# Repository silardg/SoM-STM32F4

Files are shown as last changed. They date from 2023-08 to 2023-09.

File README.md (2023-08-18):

# SoM STM32F4

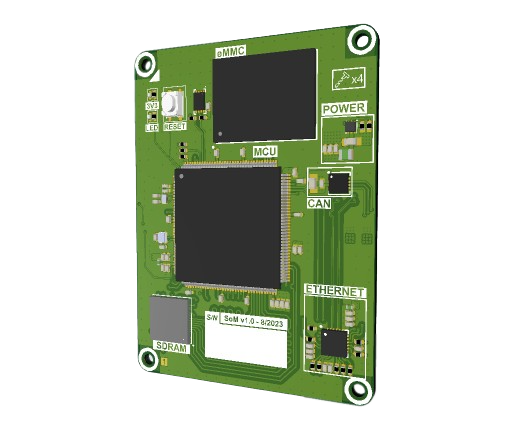
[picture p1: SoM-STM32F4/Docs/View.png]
BoardView


This System-on-Module provides a powerful platform with an STM32F429 extended by an SDRAM, eMMC and external peripherals like Ethernet and CAN Bus. 
The SoM plugs into a motherboard through its low-profile connectors.

The size of the board is 60mm x 45mm with an 8 layer stackup. 

## Components
- **MCU** - STM32F429ZET6TR
- **SDRAM** - AS4C8M16SA-6BINTR
- **eMMC** - IS21TF08G-JQLI
- **Secure Element** - ATECC608A-MAHDA-S
- **Ethernet** - LAN8720A-CP-ABC
- **CAN Bus** - LTC2875HDD#TRPBF

## Board Views
### Top View
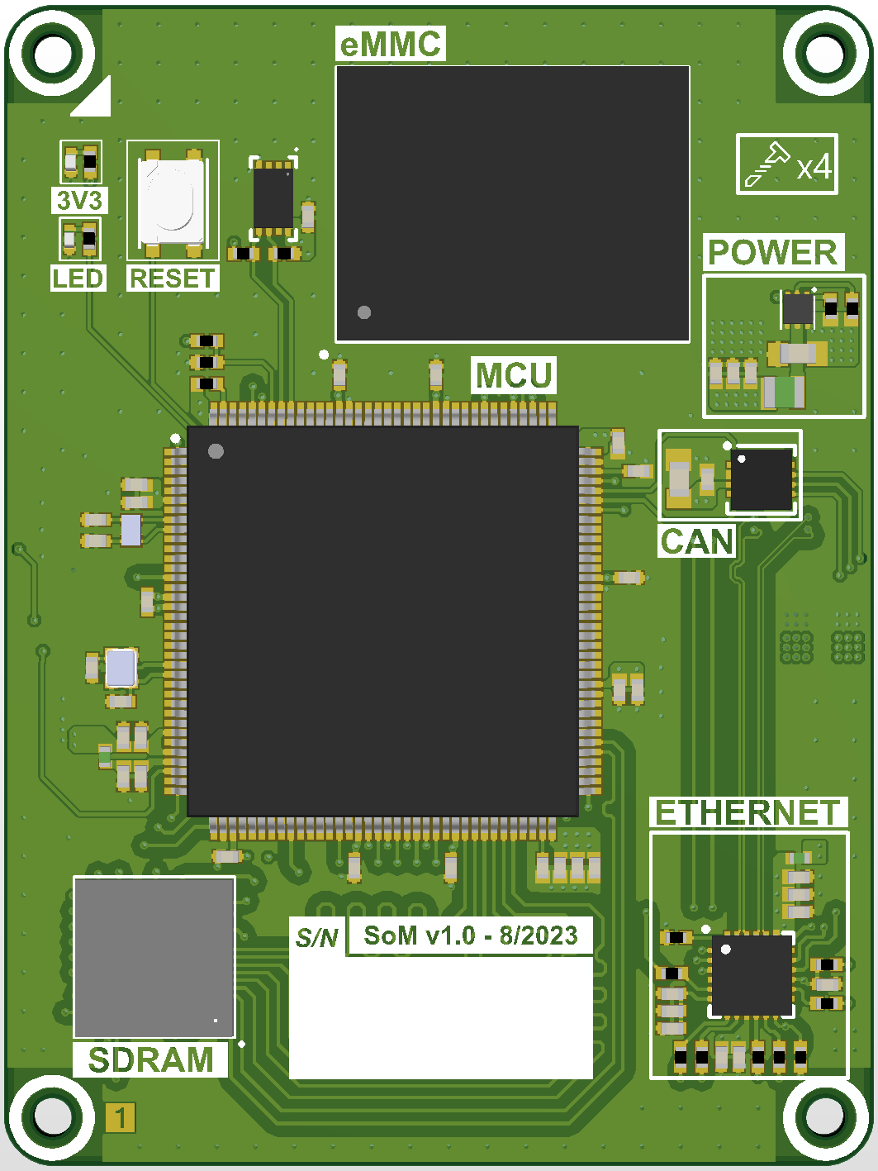
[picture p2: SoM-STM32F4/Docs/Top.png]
Top

### Bottom View
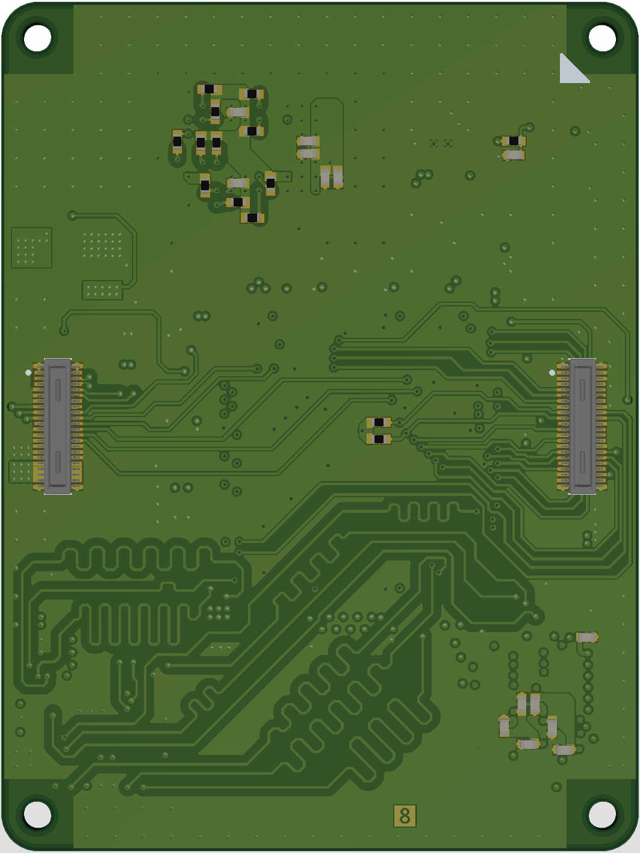
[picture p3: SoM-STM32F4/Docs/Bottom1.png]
Bottom

### Bottom Fancy View
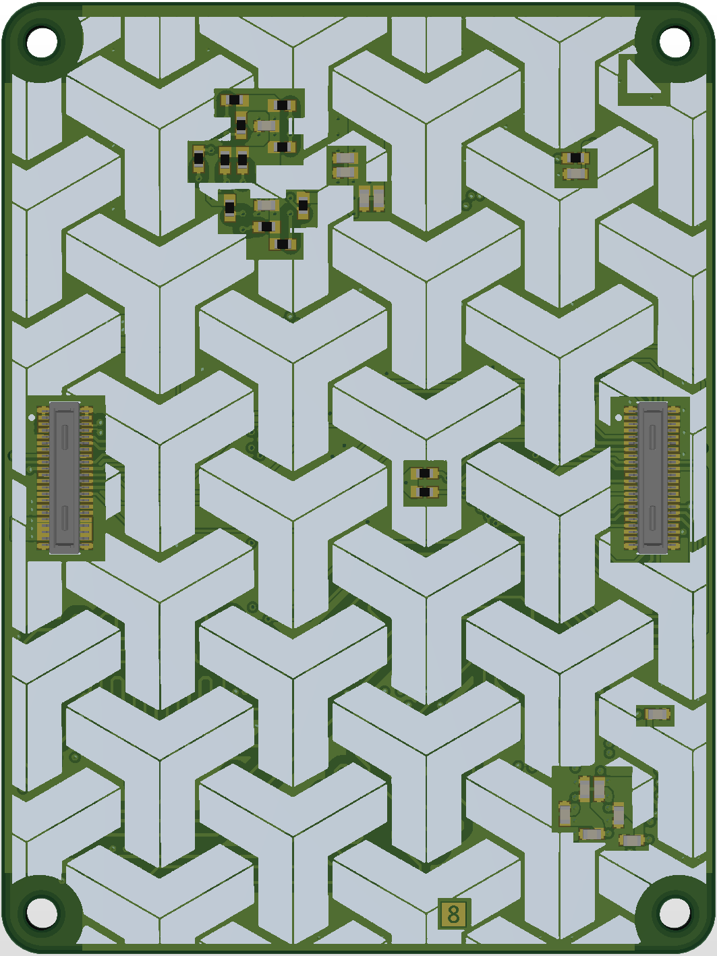
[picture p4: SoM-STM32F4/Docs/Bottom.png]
Bottom


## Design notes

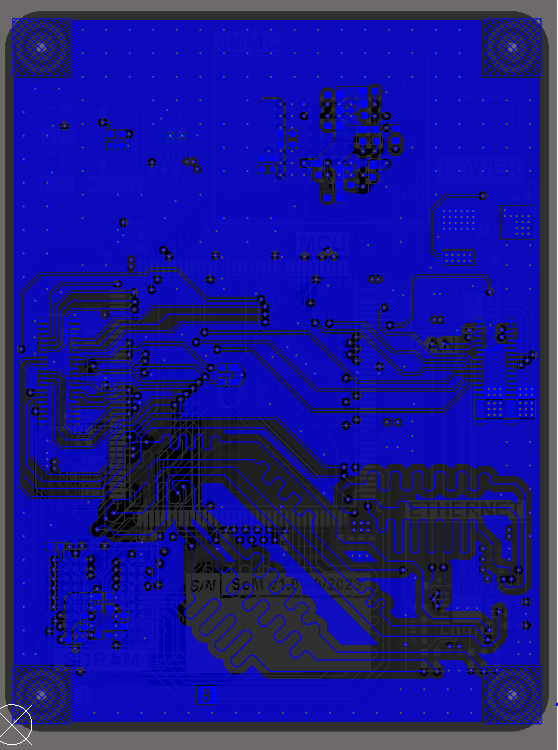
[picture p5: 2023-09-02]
SoM-STM32F4/Docs/8thLayer.PNG

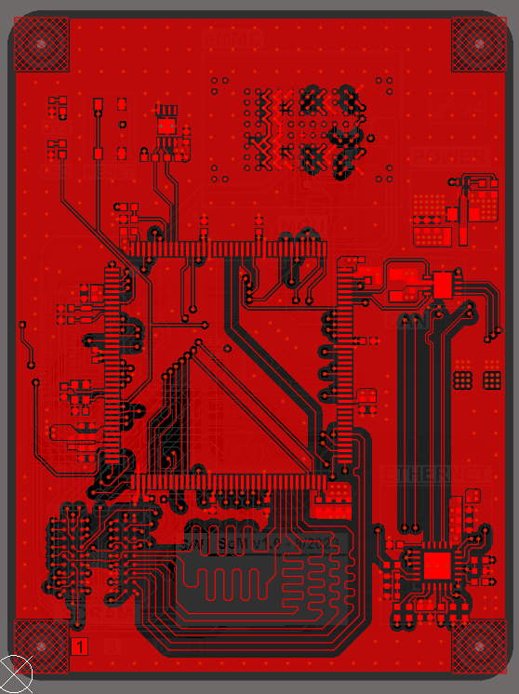
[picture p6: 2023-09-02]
SoM-STM32F4/Docs/1stLayer.PNG

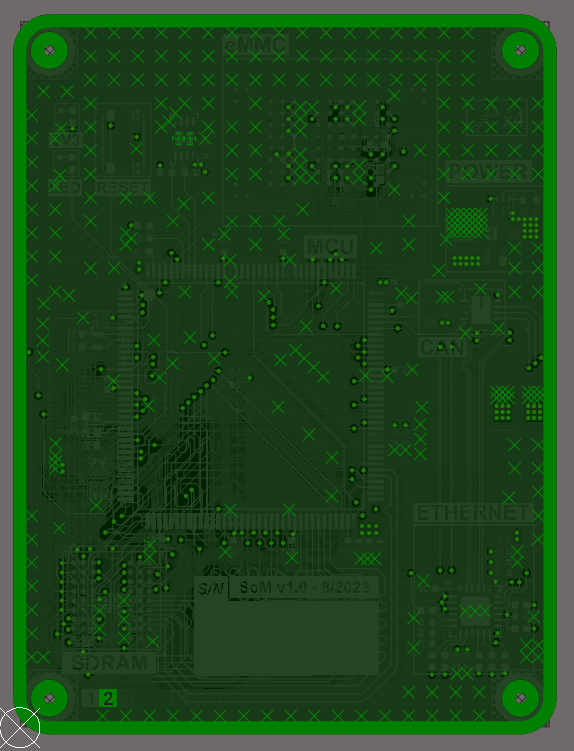
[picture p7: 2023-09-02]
SoM-STM32F4/Docs/2ndLayer.PNG

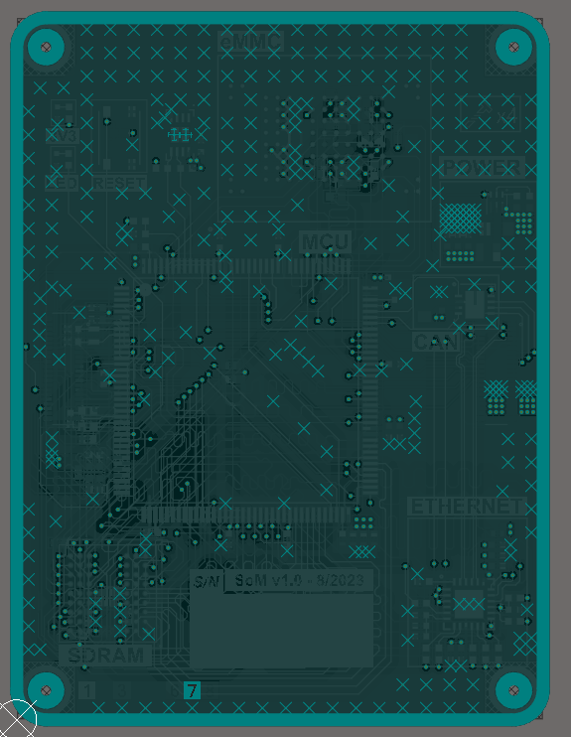
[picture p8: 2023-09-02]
SoM-STM32F4/Docs/7thLayer.PNG

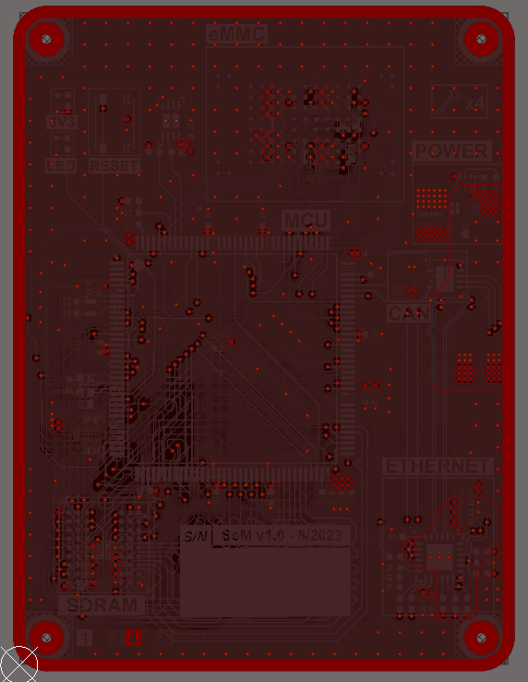
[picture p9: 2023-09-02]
SoM-STM32F4/Docs/4thLayer.PNG

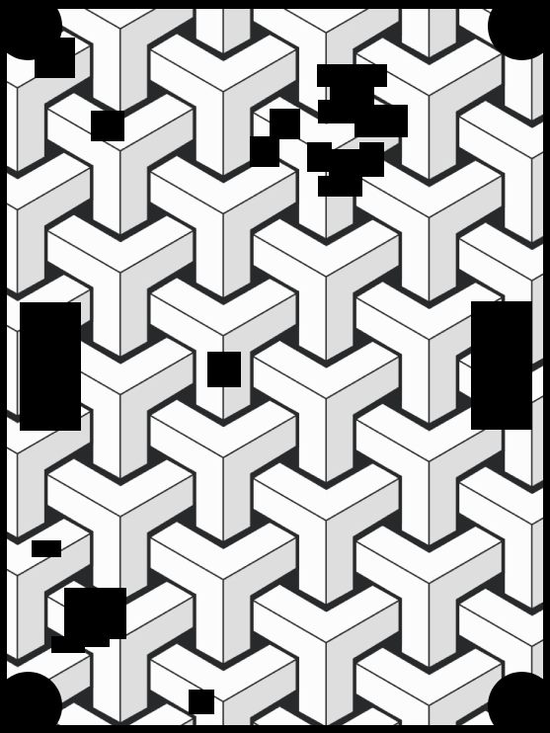
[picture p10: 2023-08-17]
SoM-STM32F4/Docs/Background.jpg

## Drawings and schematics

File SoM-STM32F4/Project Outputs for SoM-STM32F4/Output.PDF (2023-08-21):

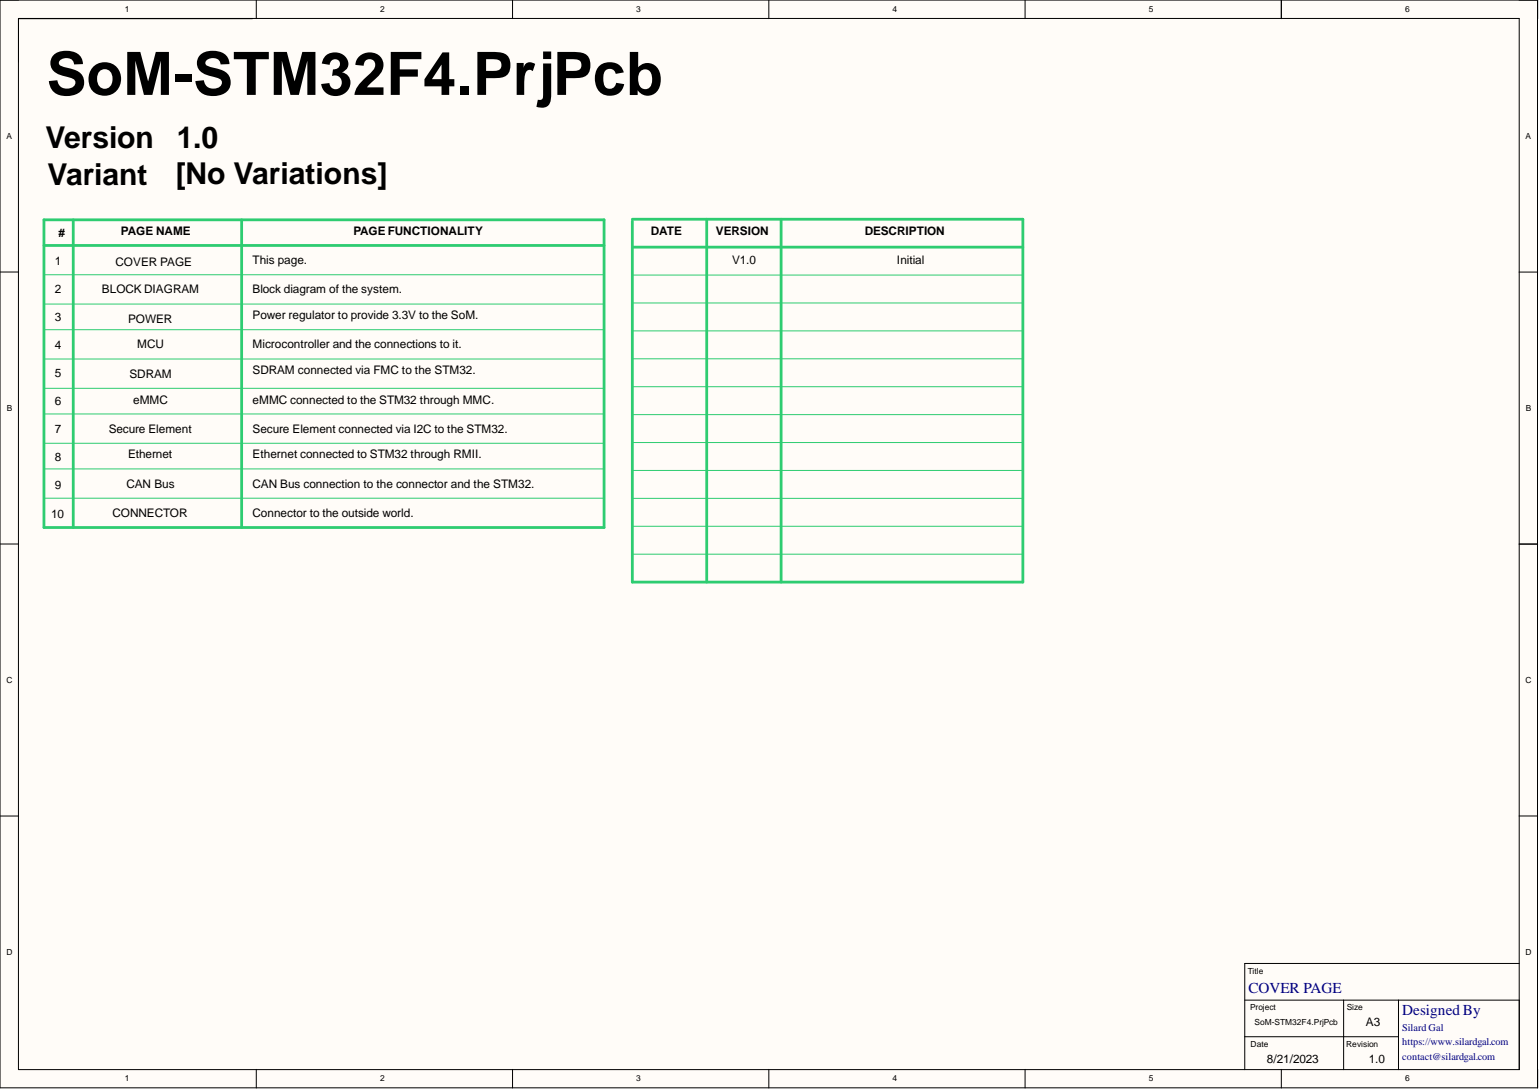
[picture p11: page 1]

3 | POWER | Power regulator to provide 3.3V to the SoM.

4 | MCU | Microcontroller and the connections to it.

5 | SDRAM | SDRAM connected via FMC to the STM32.

6 | eMMC | eMMC connected to the STM32 through MMC.

7 | Secure Element | Secure Element connected via I2C to the STM32.

8 | Ethernet | Ethernet connected to STM32 through RMII.

9 | CAN Bus | CAN Bus connection to the connector and the STM32.

10 | CONNECTOR | Connector to the outside world.

Project SoM-STM32F4.PrjPcb | Size A3 | Designed By Silard Gal https://www.silardgal.com contact@silardgal.com

Date 8/21/2023 | Revision 1.0

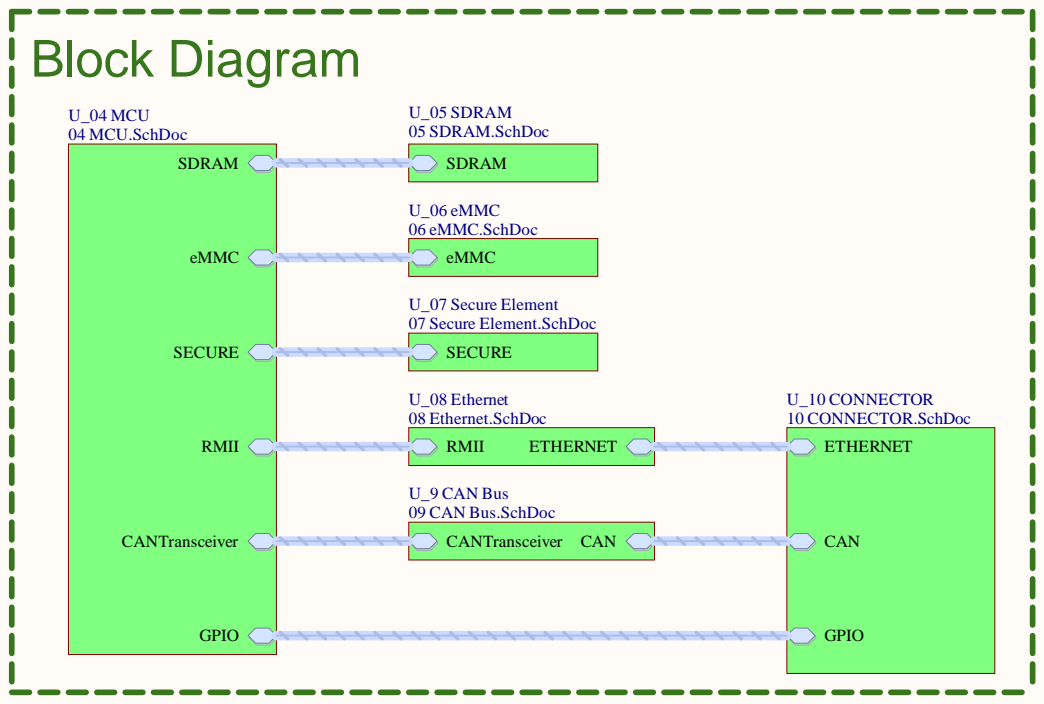
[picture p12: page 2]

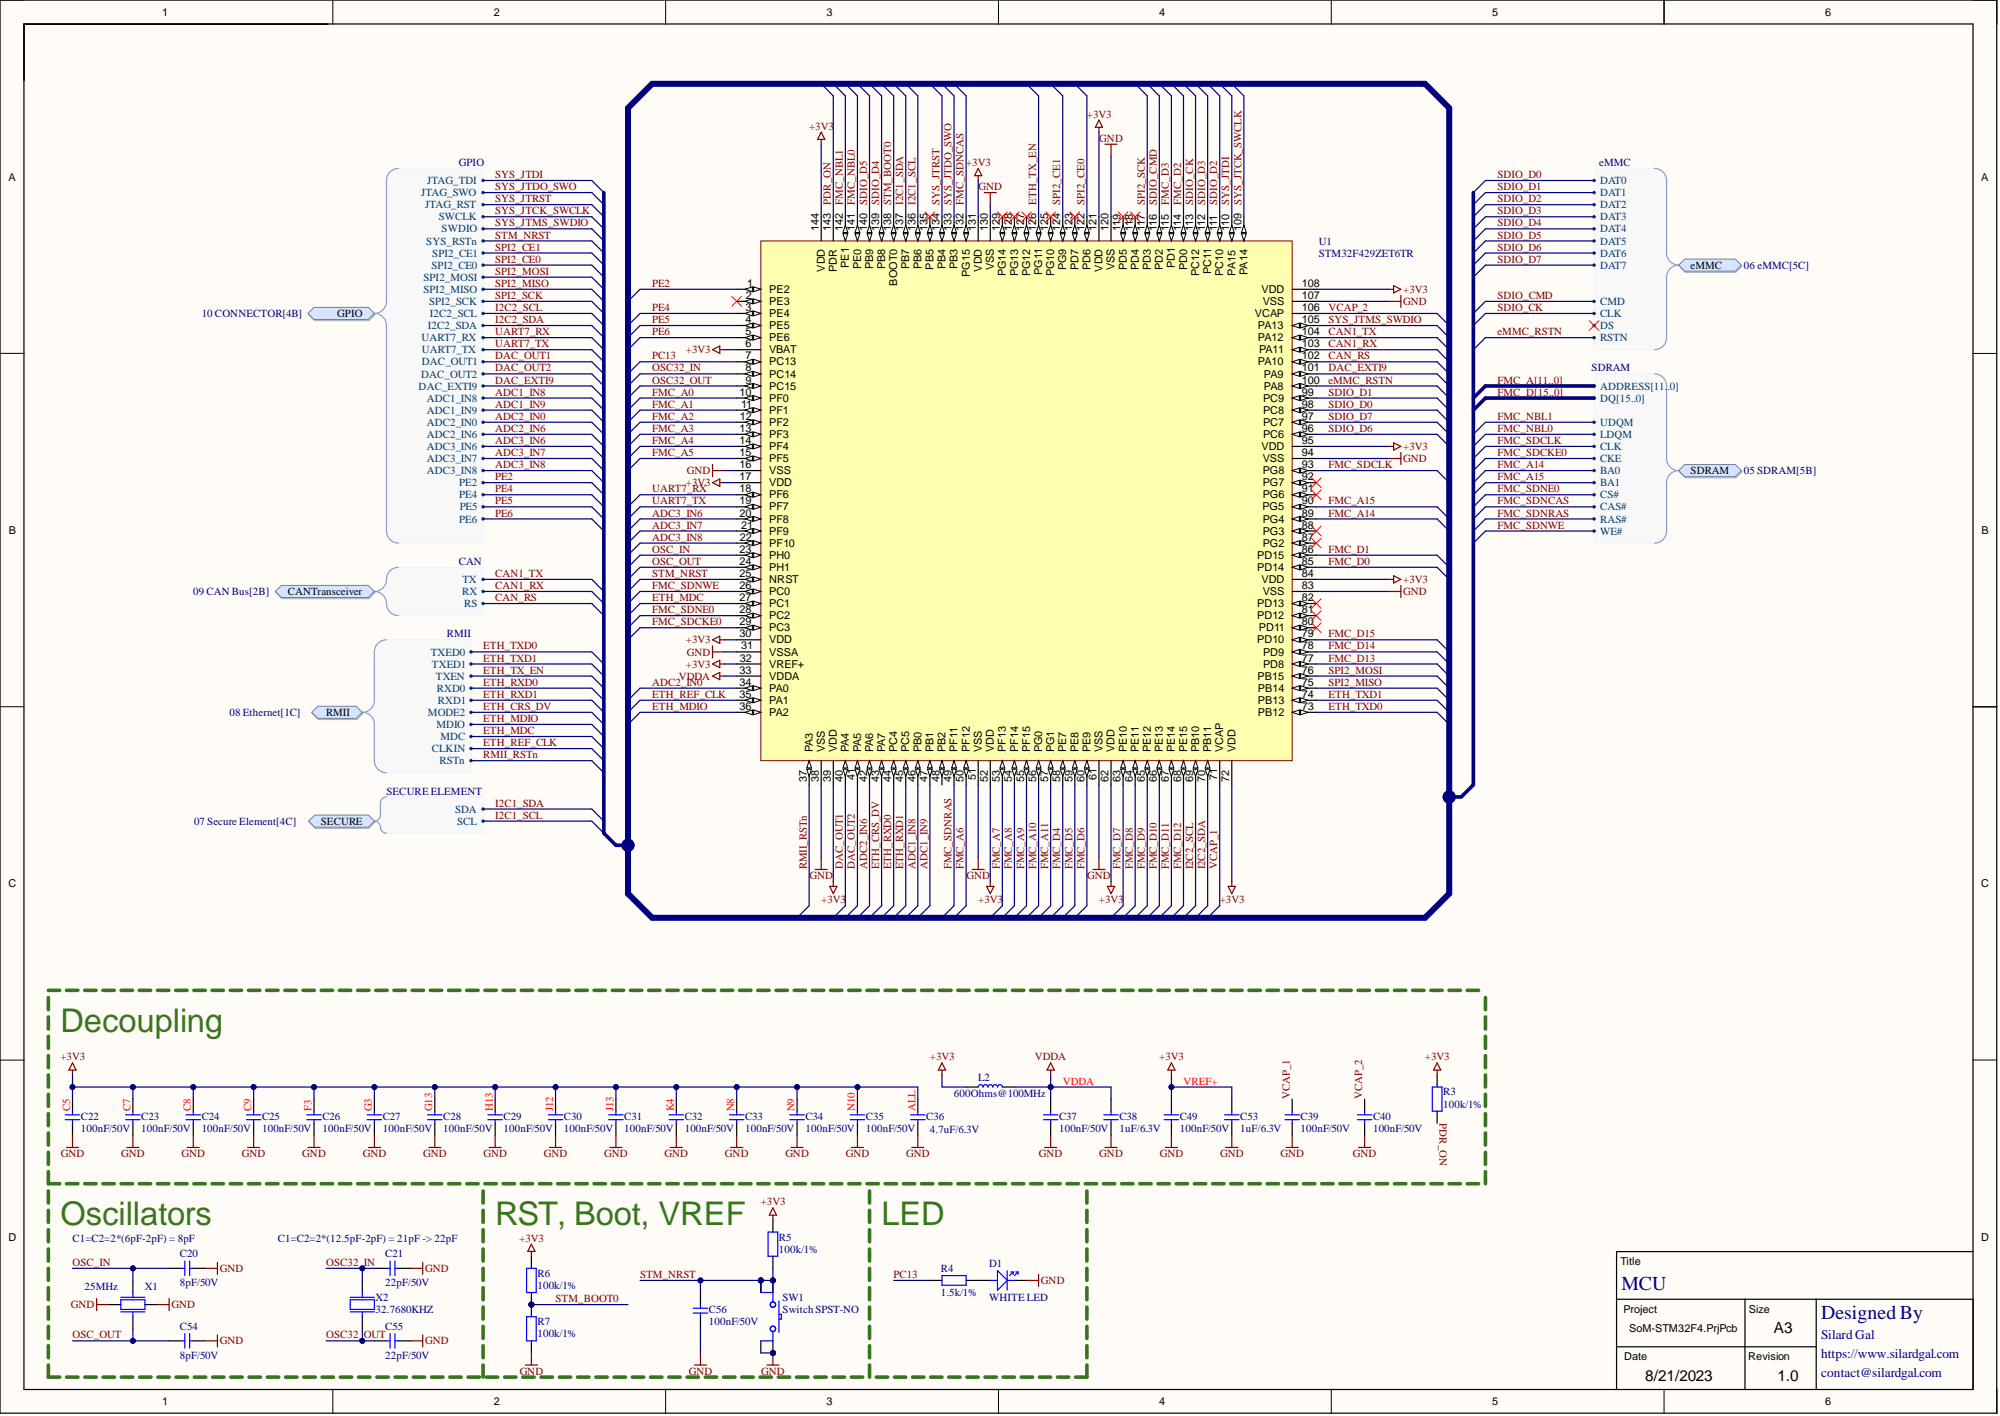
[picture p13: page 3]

PA14 109 PA15 110 PC10 111 PC11 112 PC12 113 PD0 114 PD1 115 PD2 116 PD3 117 PD4 118 PD5 119 VSS 120 VDD 121 PD6 122 PD7 123 PG9 124 PG10 125 PG11 126 PG12 127 PG13 128 PG14 129 VSS 130 VDD 131 PG15 132 PB3 133 PB4 134 PB5 135 PB6 136 PB7 137 BO

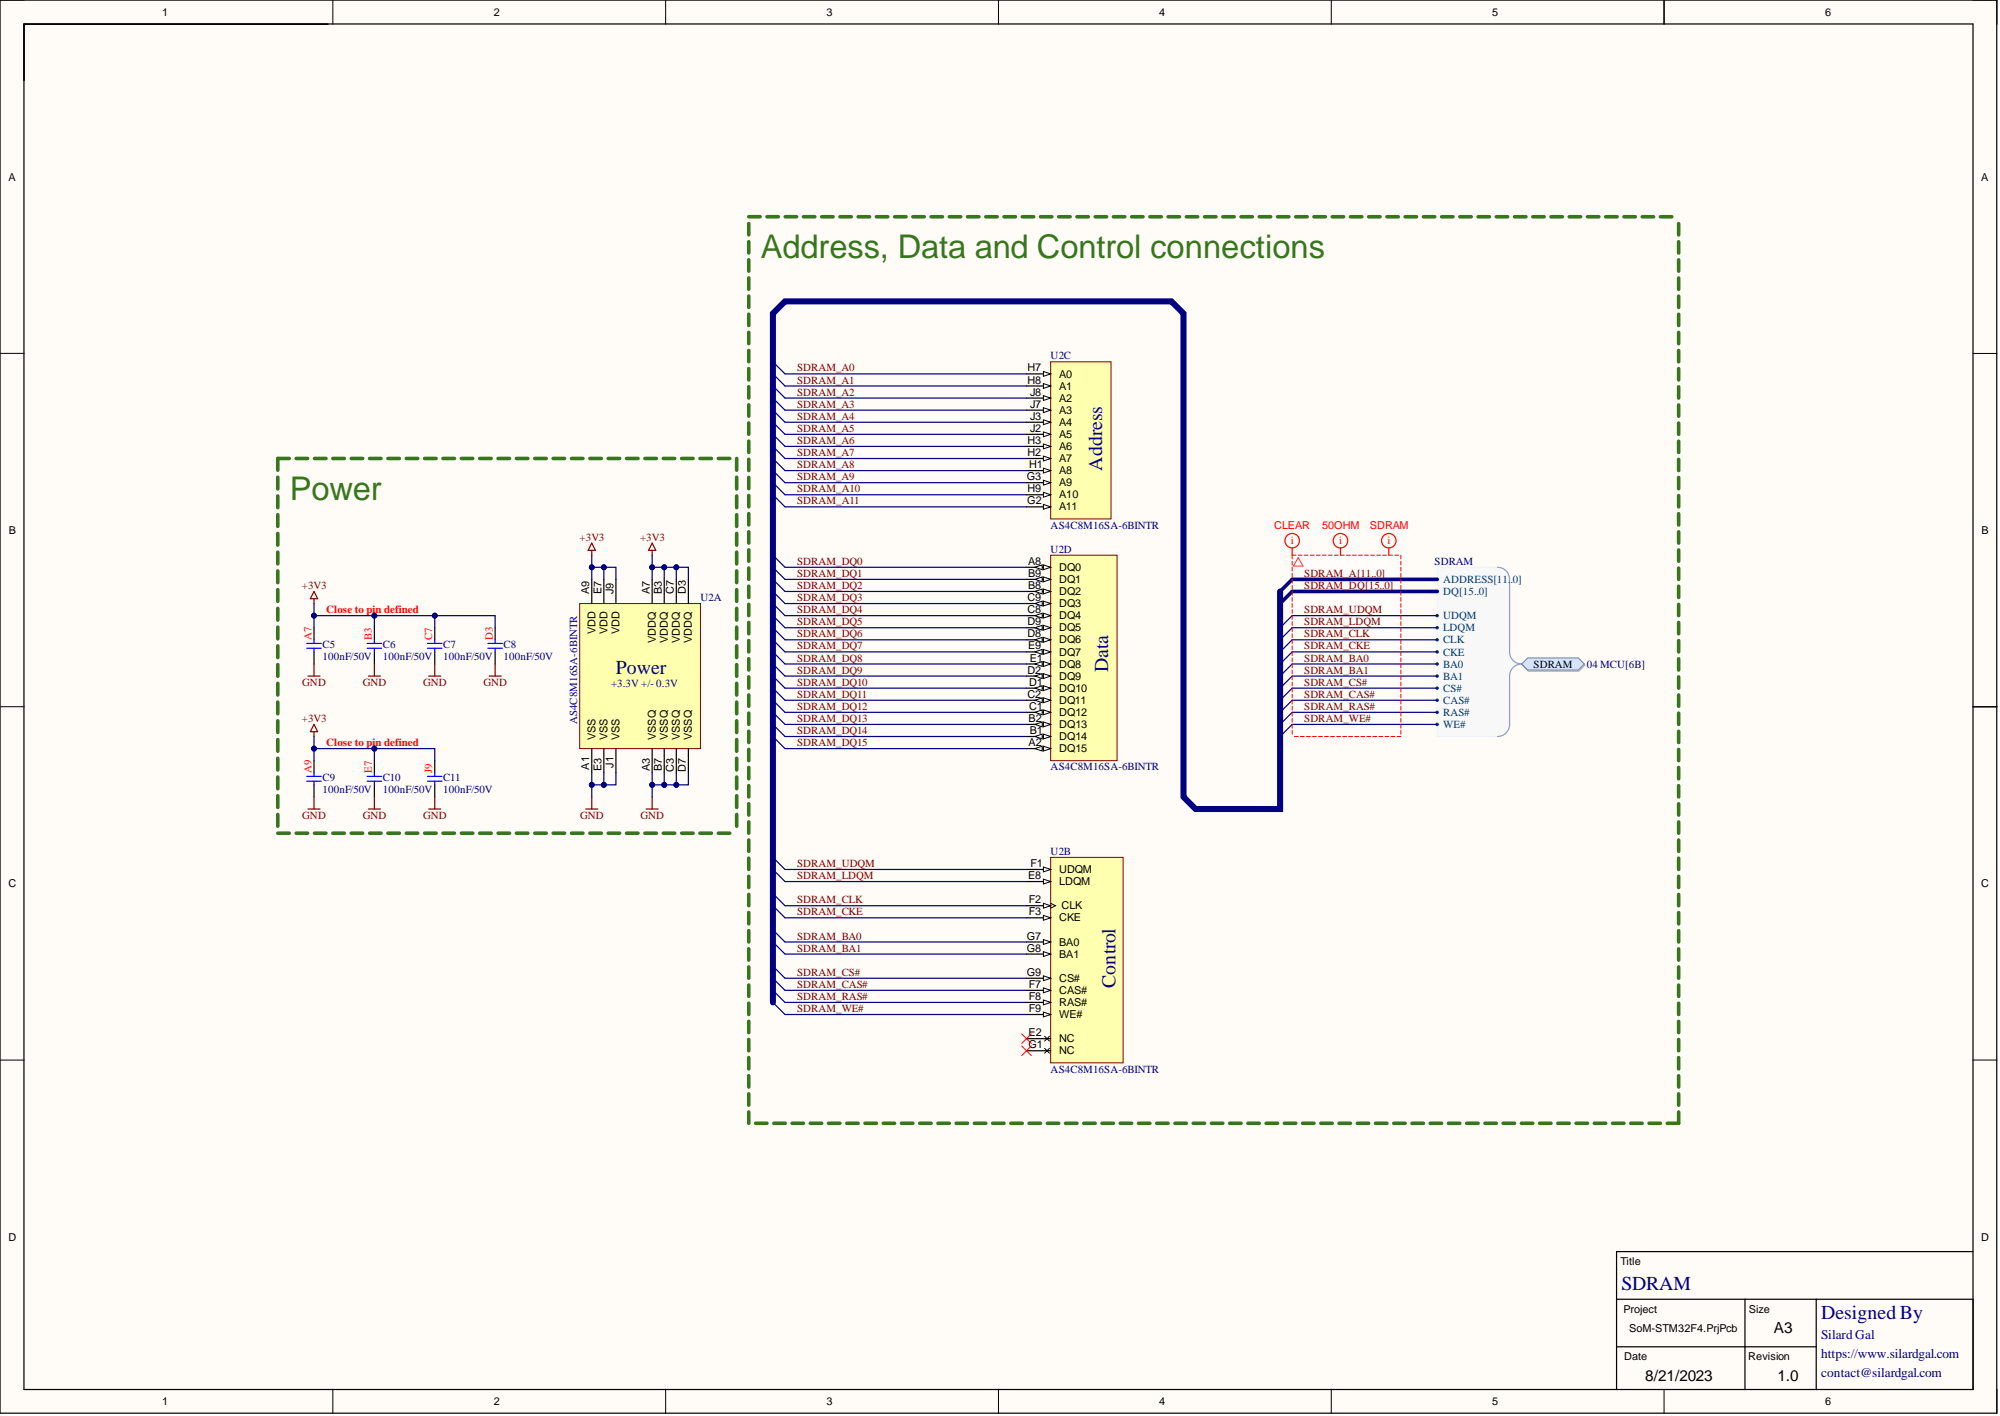
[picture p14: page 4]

Address, Data and Control connections

se to pin defined

Projec t SoM-ST M32F4.Prj P c b | Siz e | Desig ned By Silard Ga l https://www.sila rd g a . m nta ct@sila

Revis i o n

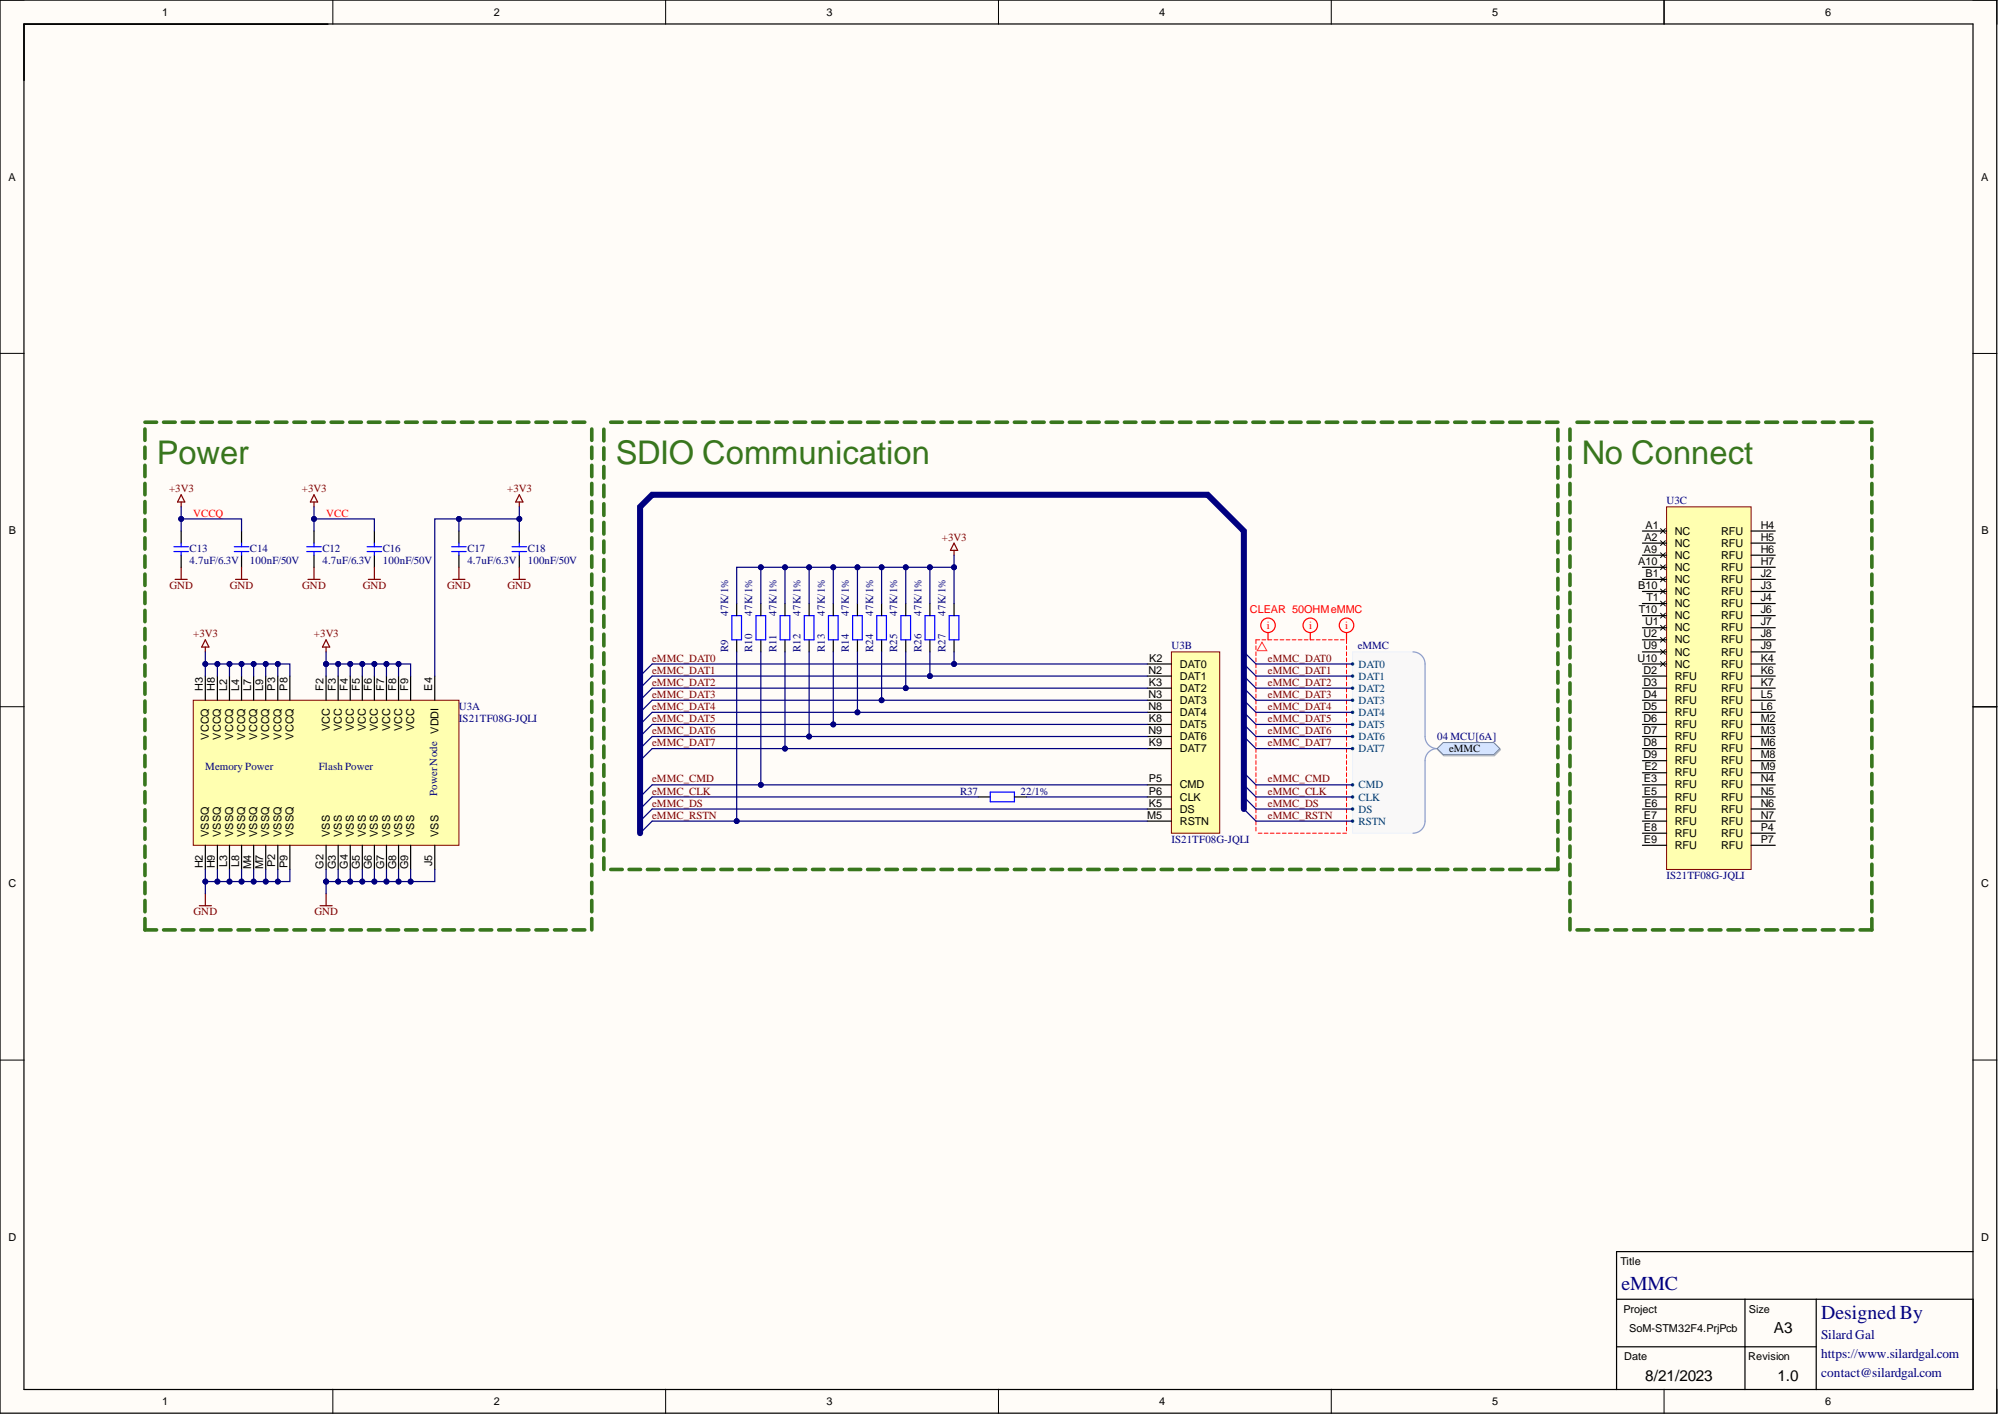
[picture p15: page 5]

VCC F5 VCC F4 VCC F3 VSS G2 VCC F2

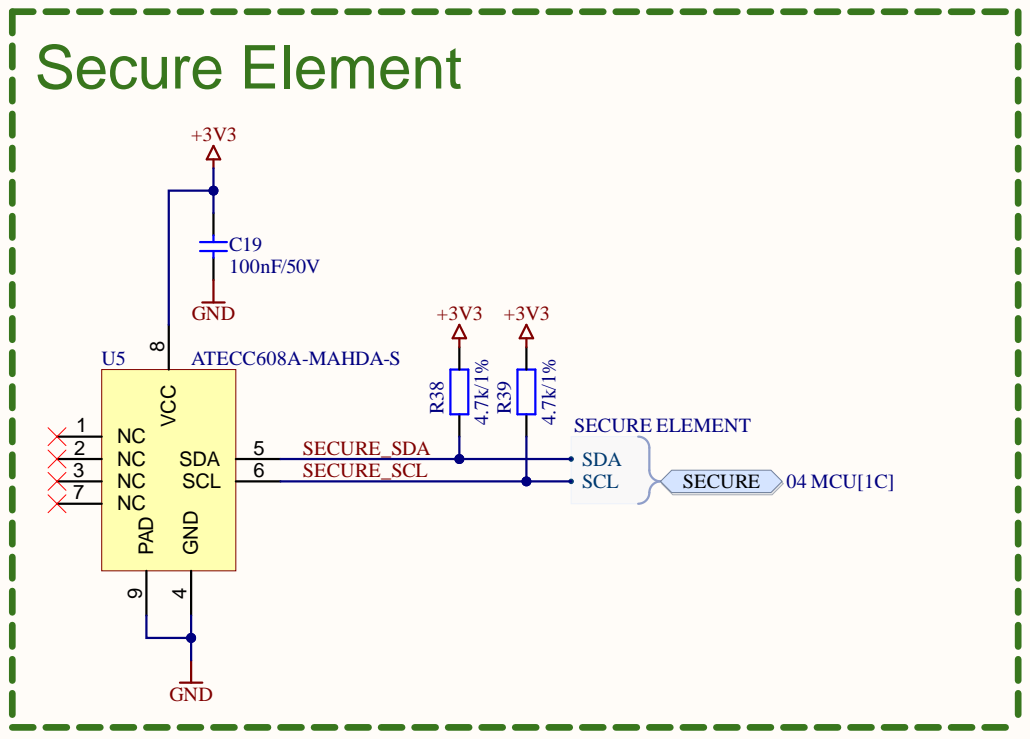
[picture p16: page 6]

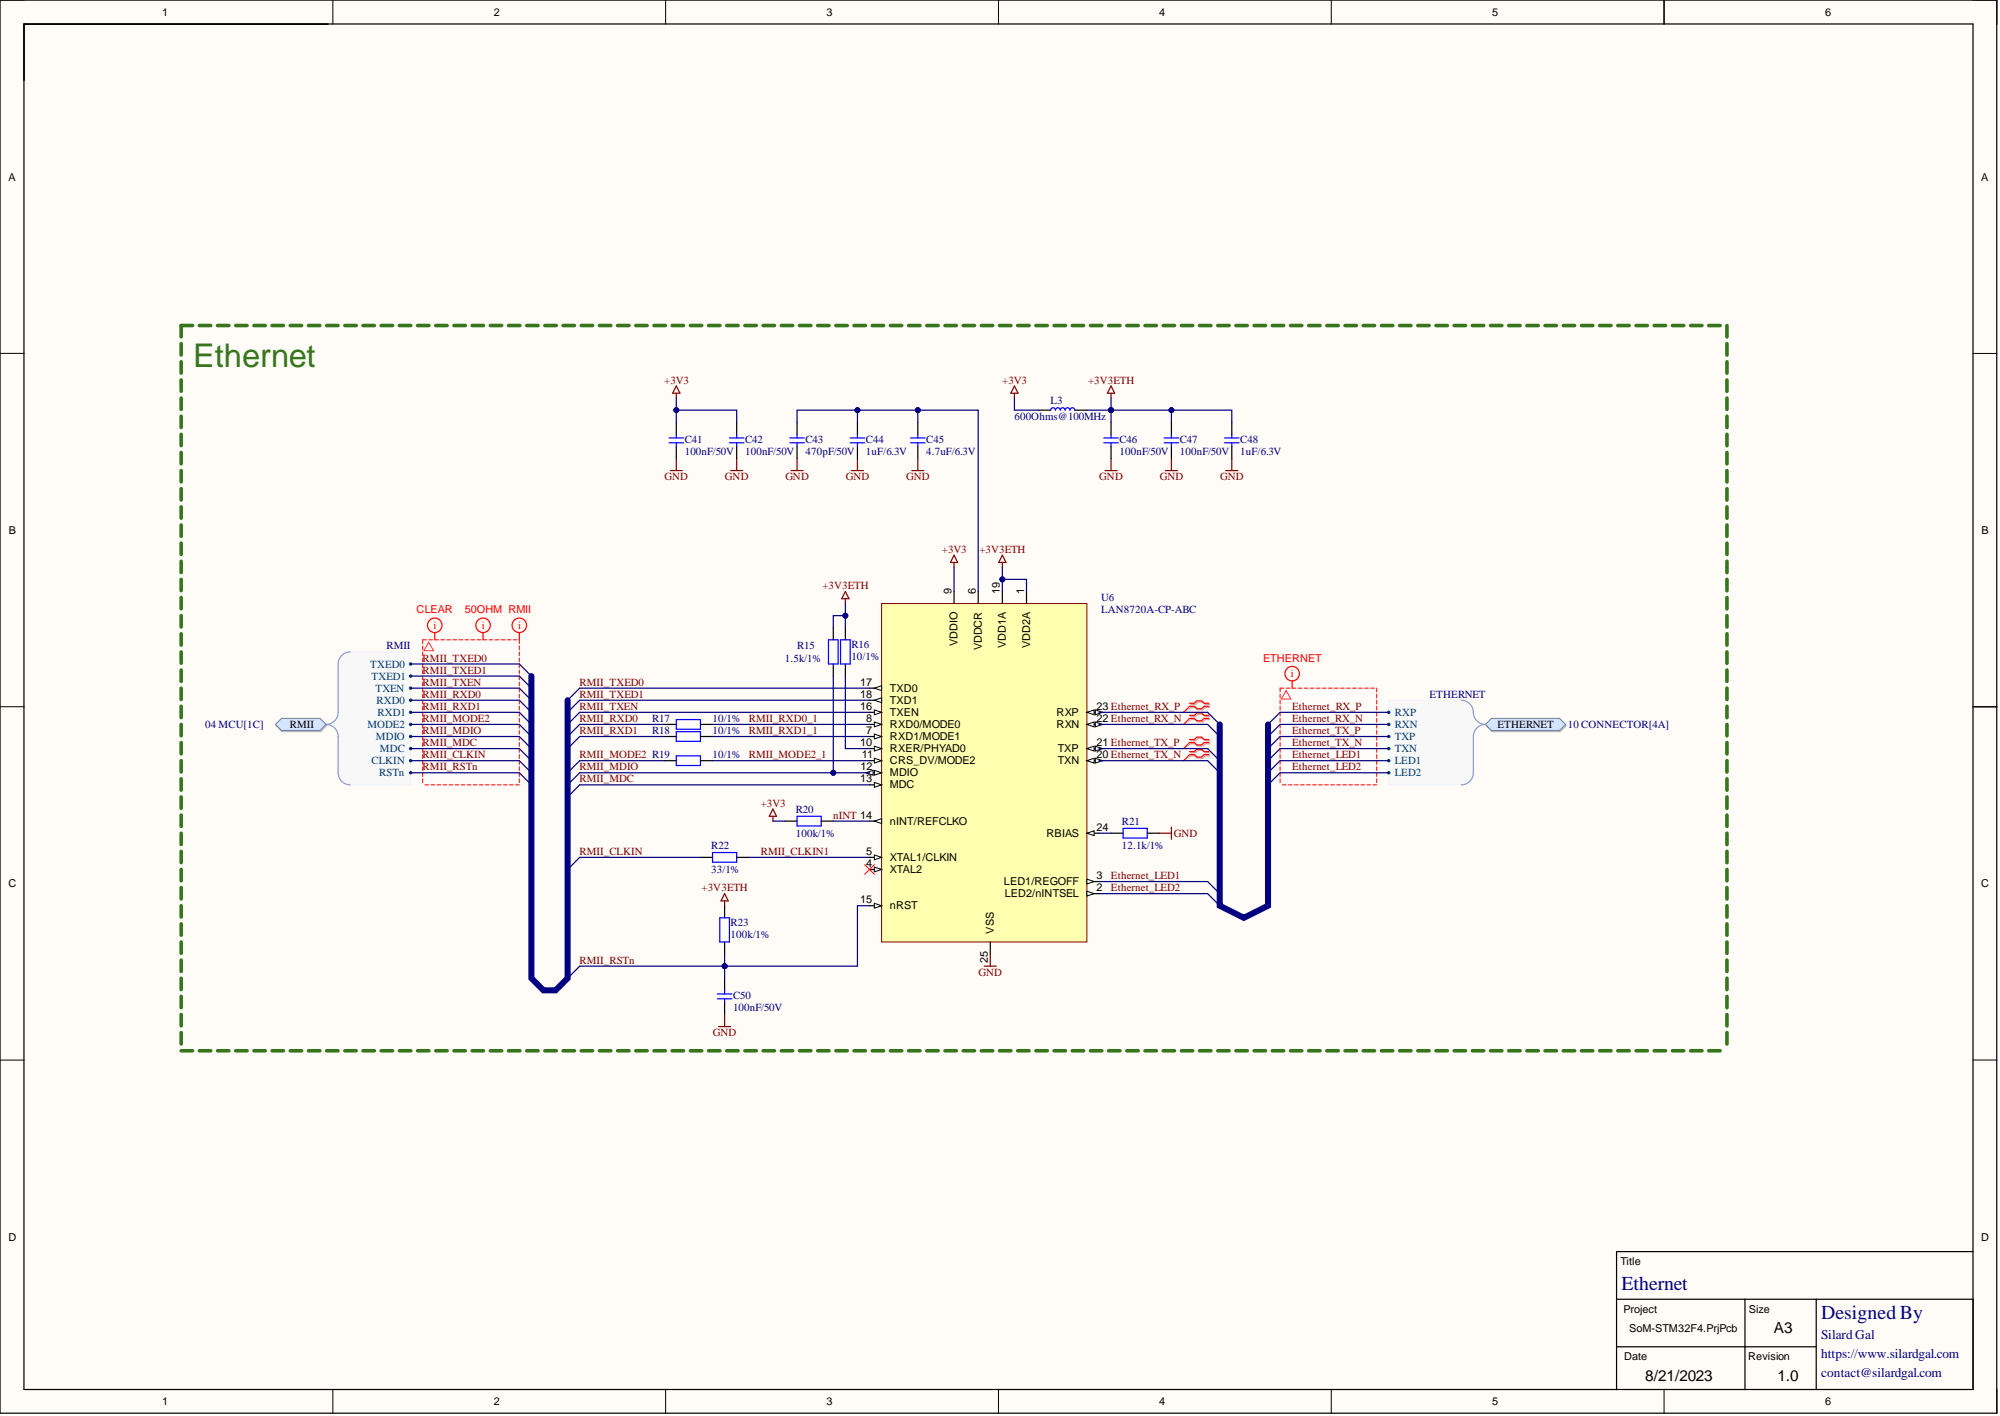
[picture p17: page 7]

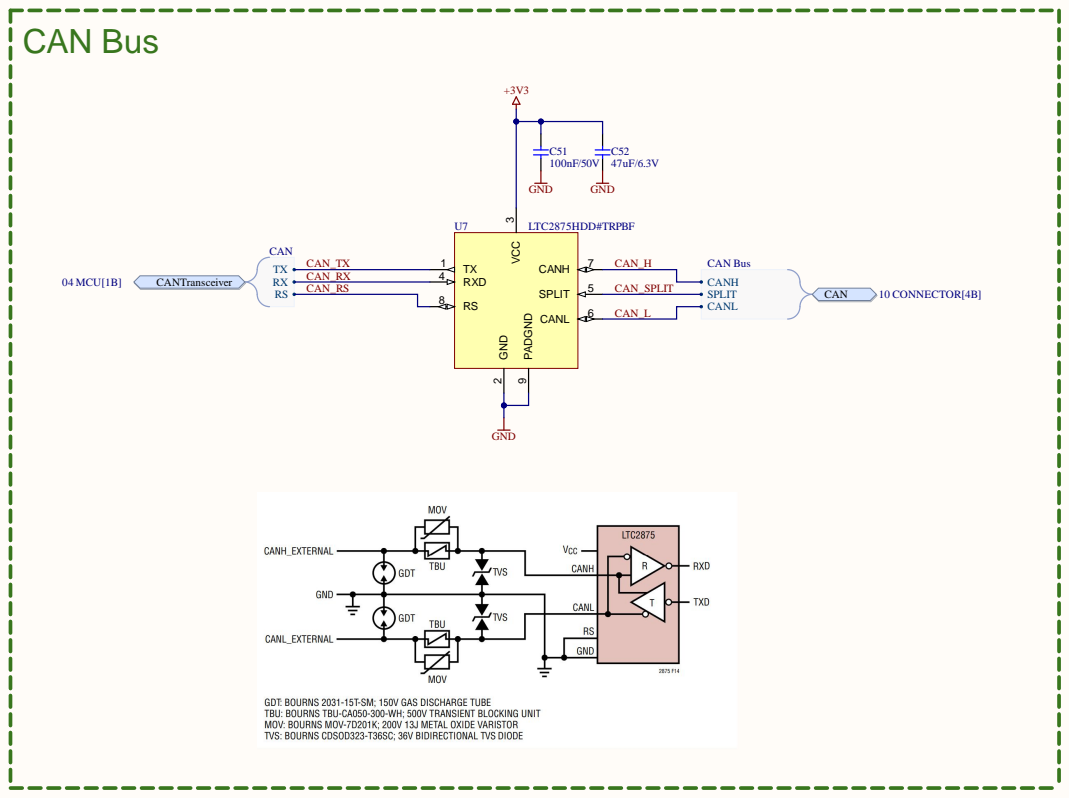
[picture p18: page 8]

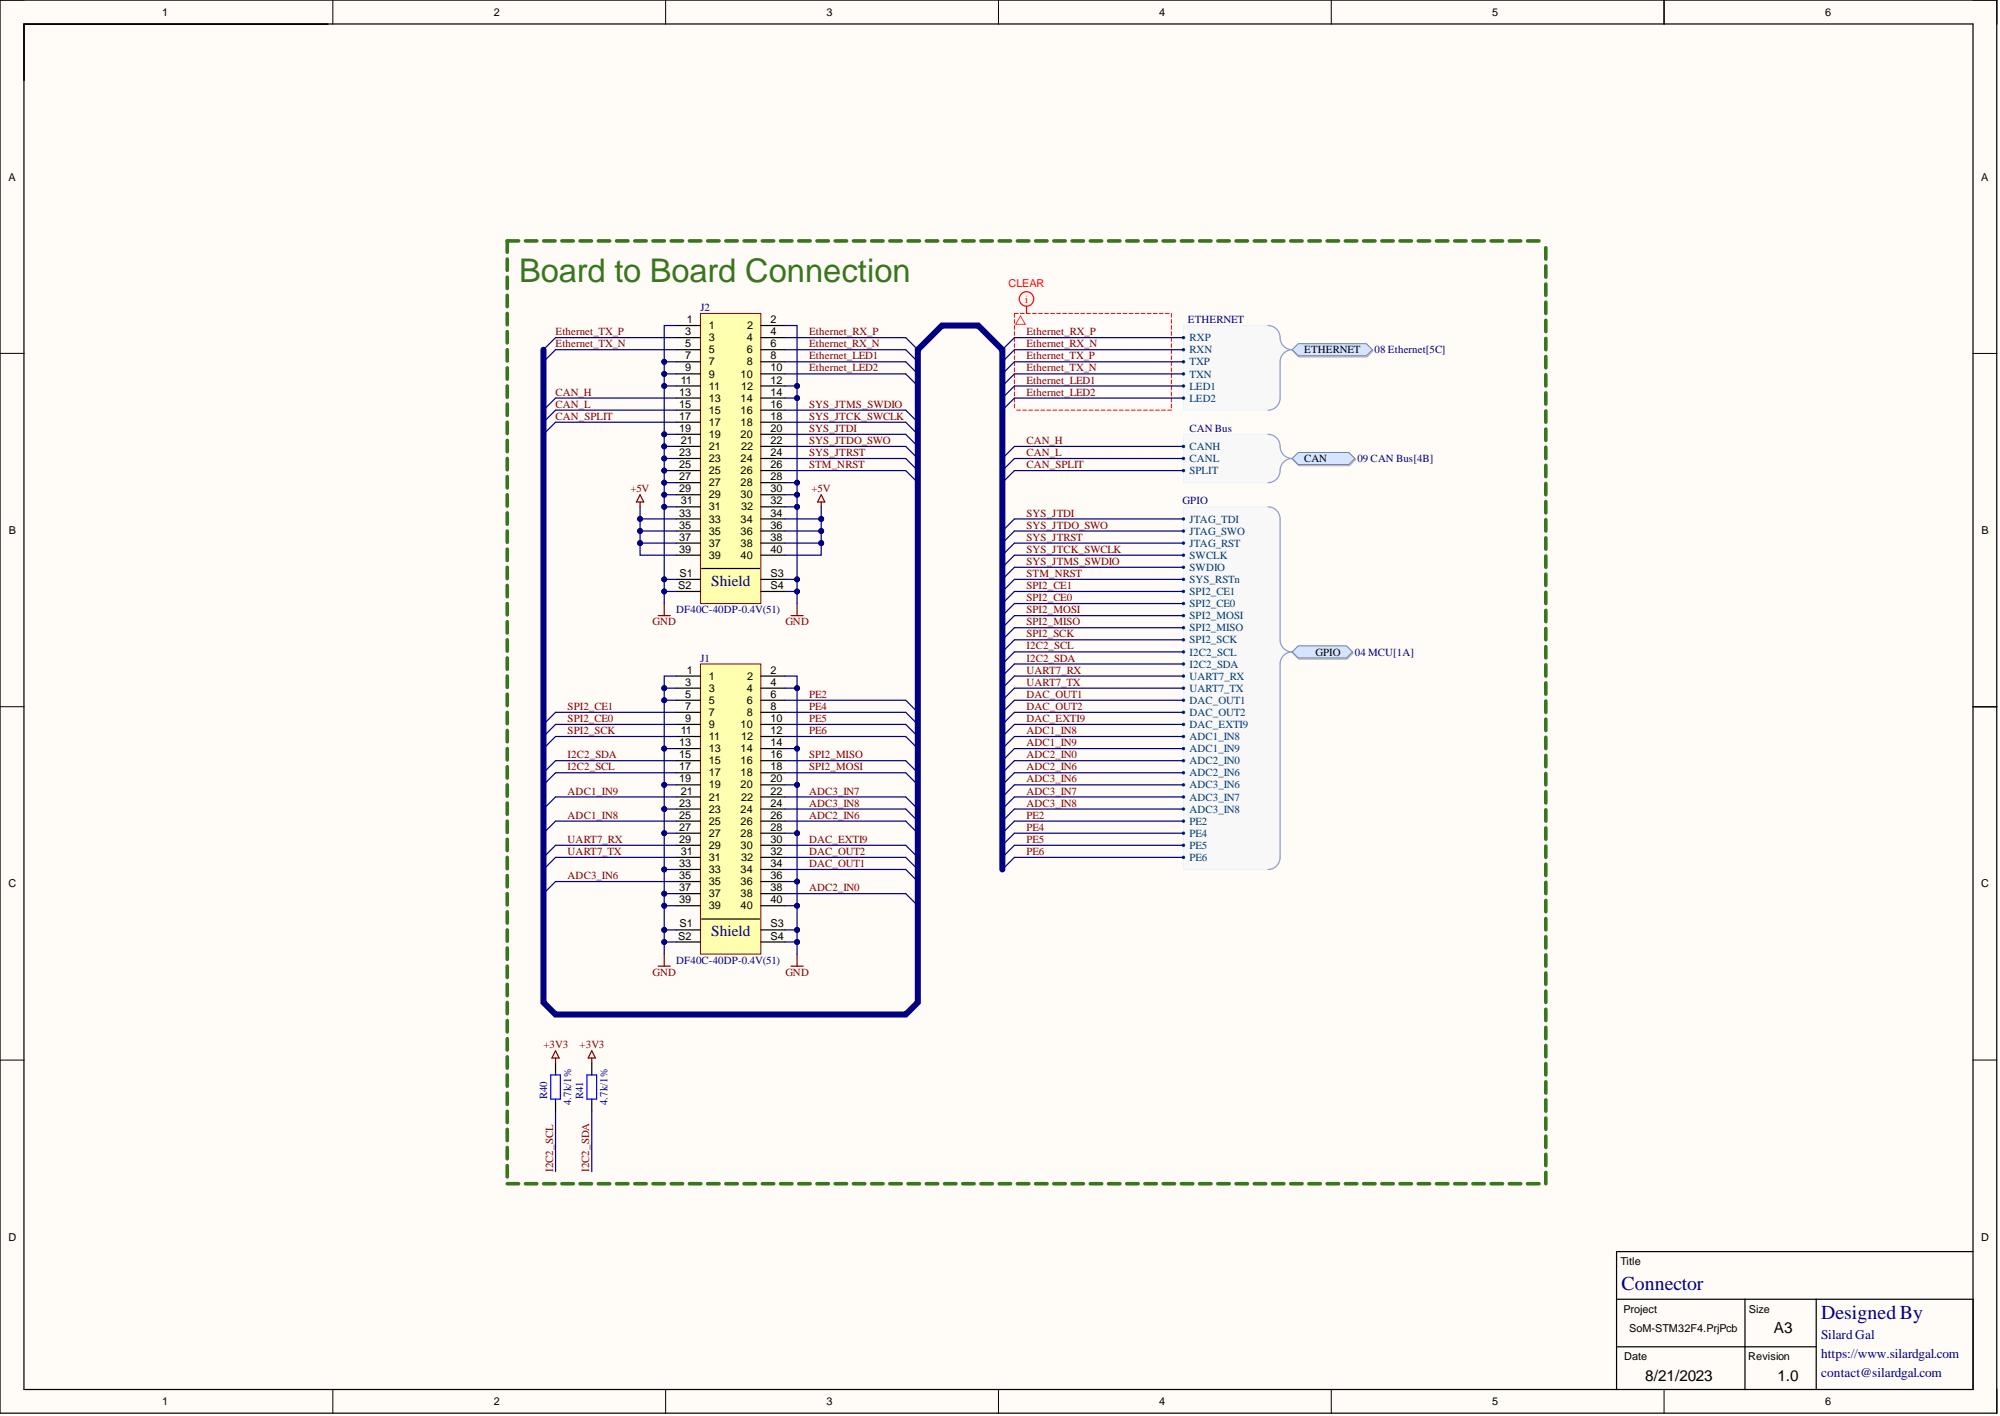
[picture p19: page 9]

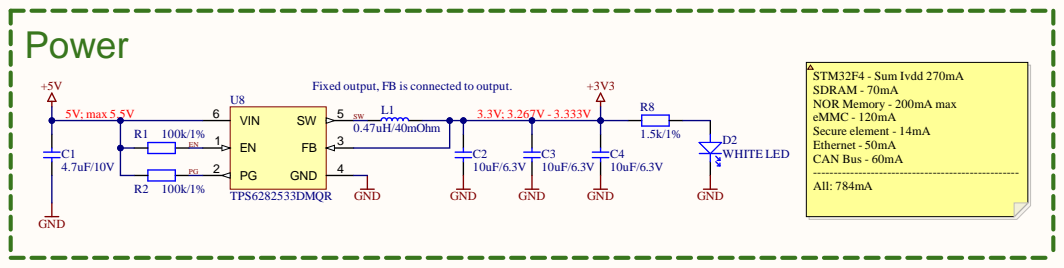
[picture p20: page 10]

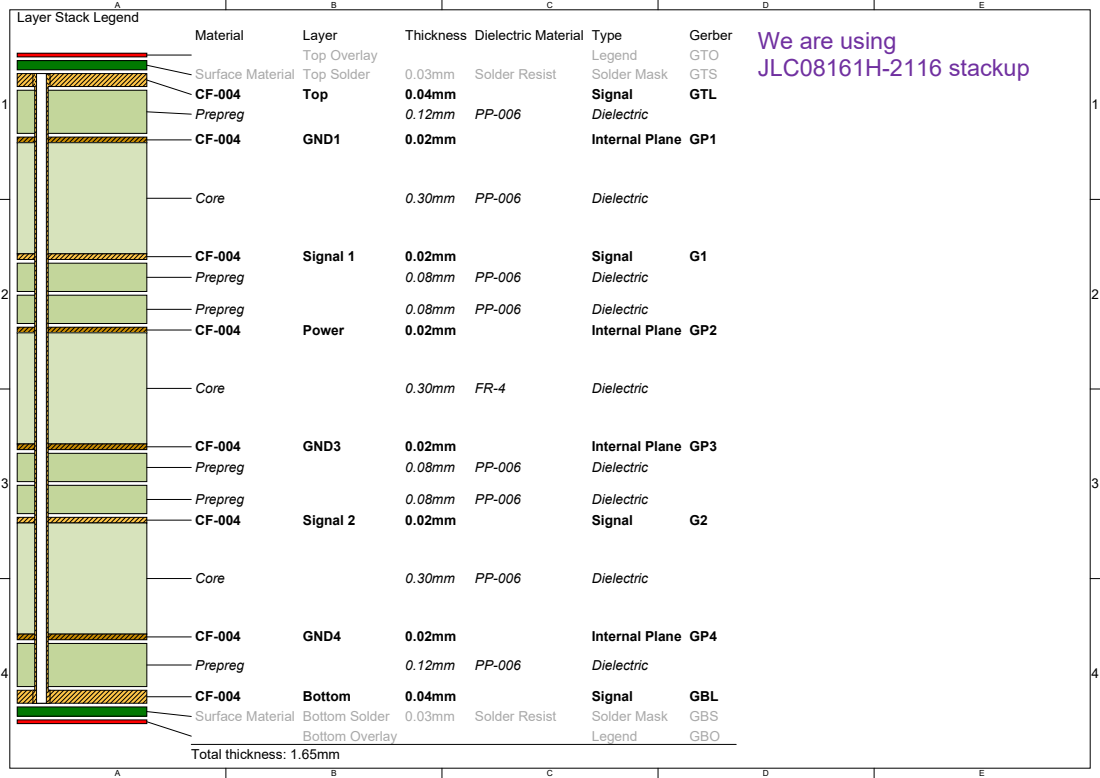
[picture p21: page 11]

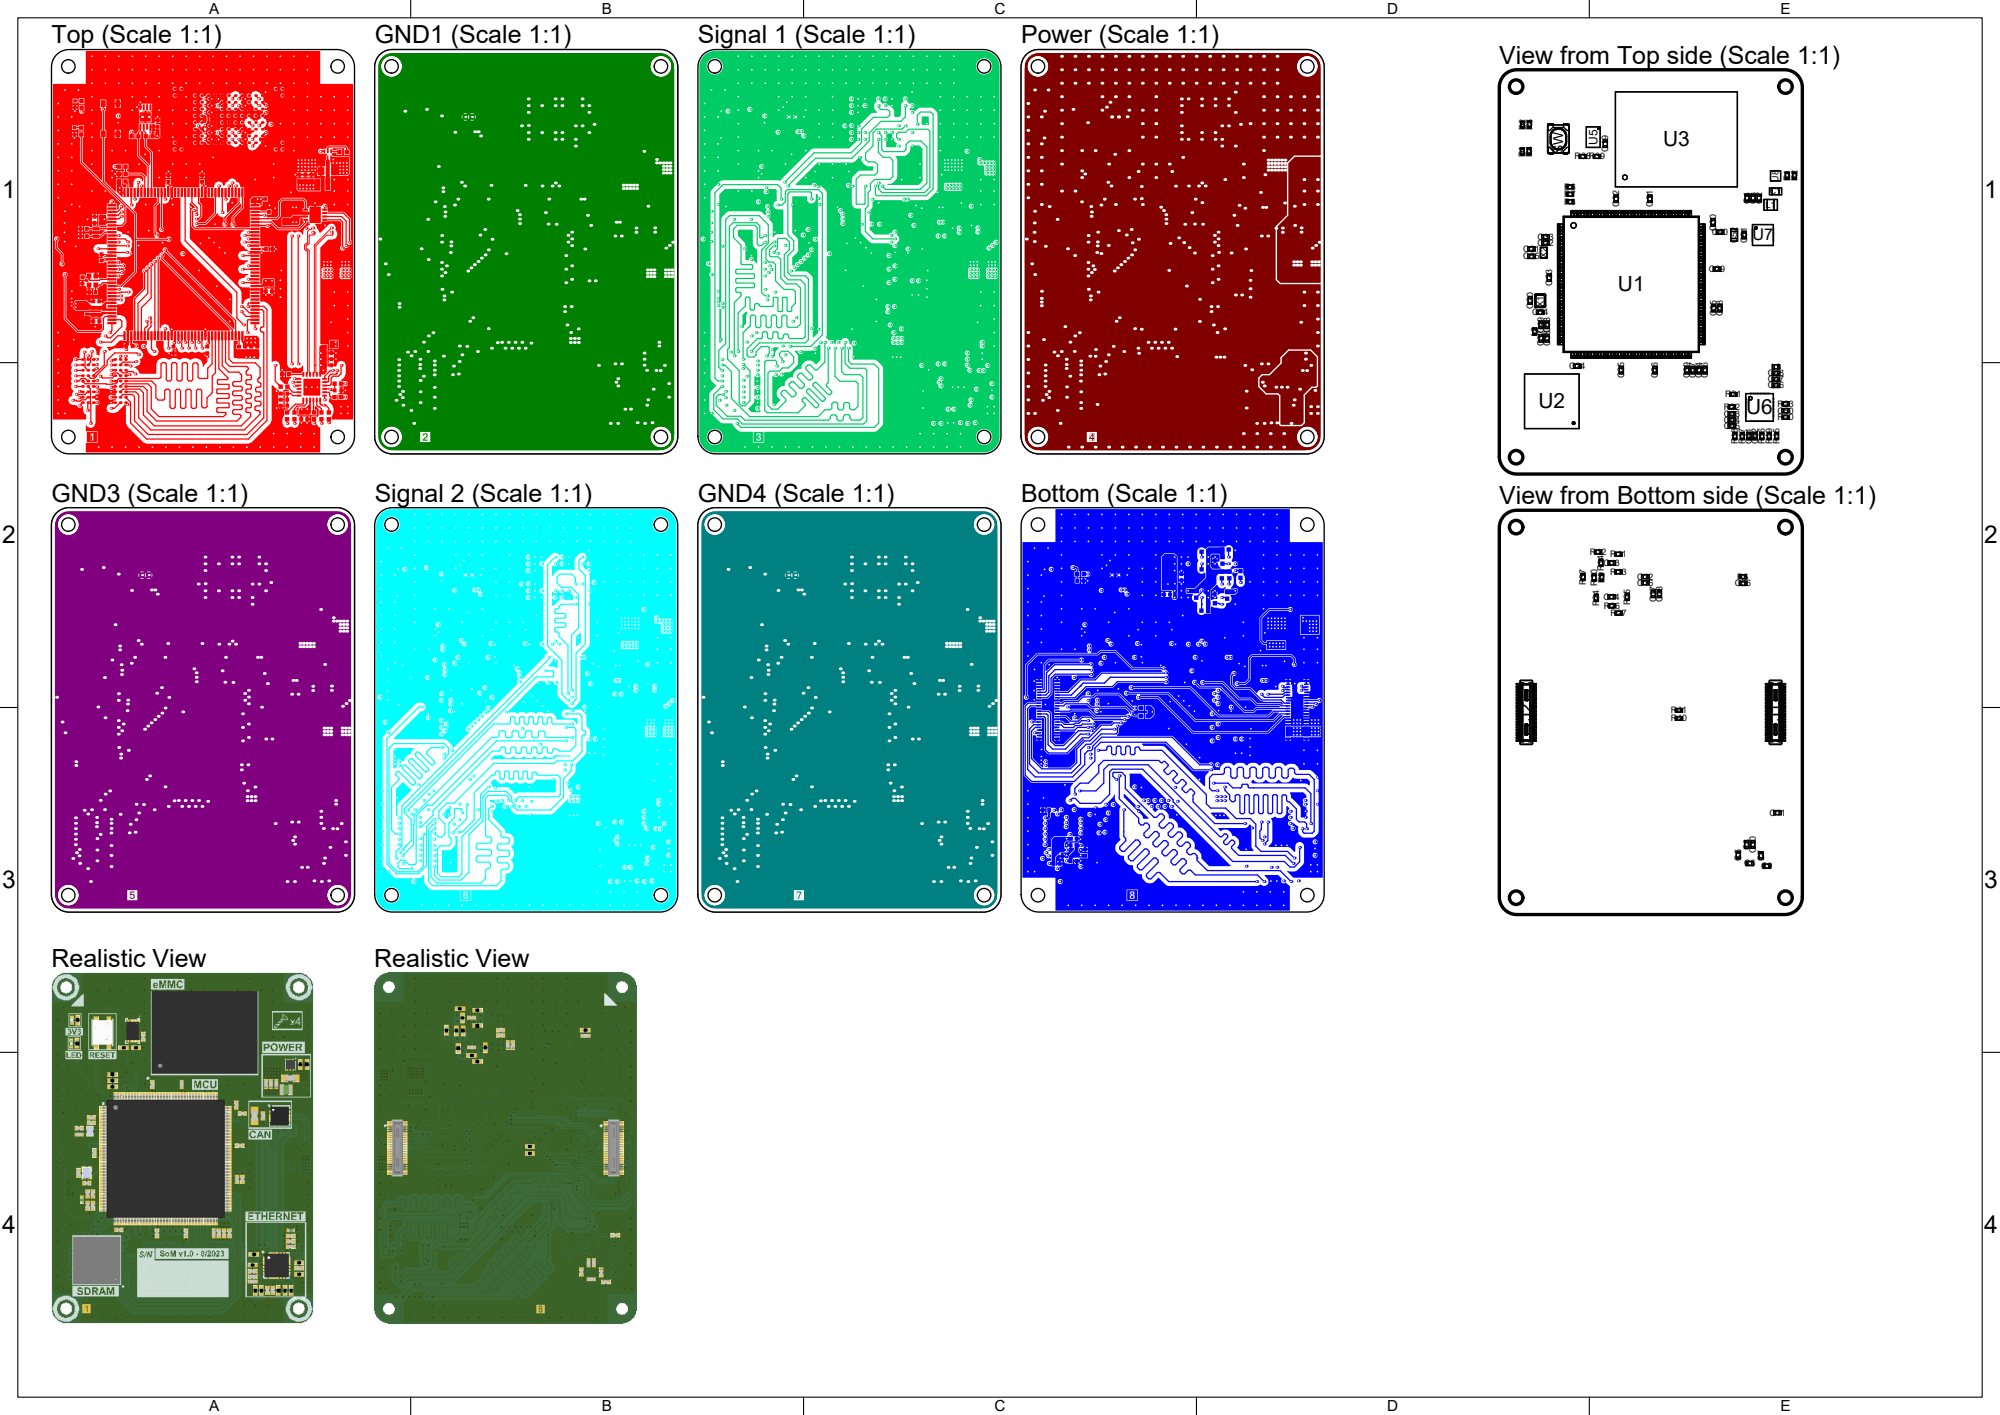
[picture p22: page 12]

View from Top side (Scale 1:1) R37

View from Bottom side (Scale 1:1)

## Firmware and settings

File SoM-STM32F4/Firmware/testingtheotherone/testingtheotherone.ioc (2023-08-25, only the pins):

Mcu.UserName=STM32F429ZETx
PA0/WKUP.Signal=ADCx_IN0
PA1.Signal=ETH_REF_CLK
PA10.Signal=GPIO_Output
PA11.Signal=CAN1_RX
PA12.Signal=CAN1_TX
PA13.Signal=SYS_JTMS-SWDIO
PA14.Signal=SYS_JTCK-SWCLK
PA15.Signal=SYS_JTDI
PA2.Signal=ETH_MDIO
PA3.Signal=GPIO_Output
PA4.Signal=COMP_DAC1_group
PA5.Signal=COMP_DAC2_group
PA6.Signal=ADCx_IN6
PA7.Signal=ETH_CRS_DV
PA8.Signal=GPIO_Output
PA9.Signal=GPXTI9
PB0.Signal=ADCx_IN8
PB1.Signal=ADCx_IN9
PB10.Signal=I2C2_SCL
PB11.Signal=I2C2_SDA
PB12.Signal=ETH_TXD0
PB13.Signal=ETH_TXD1
PB14.Signal=SPI2_MISO
PB15.Signal=SPI2_MOSI
PB3.Signal=SYS_JTDO-SWO
PB4.Signal=SYS_JTRST
PB6.Signal=I2C1_SCL
PB7.Signal=I2C1_SDA
PB8.Signal=SDIO_D4
PB9.Signal=SDIO_D5
PC0.Signal=FMC_SDNWE
PC1.Signal=ETH_MDC
PC10.Signal=SDIO_D2
PC11.Signal=SDIO_D3
PC12.Signal=SDIO_CK
PC13.Signal=GPIO_Output
PC14/OSC32_IN.Signal=RCC_OSC32_IN
PC15/OSC32_OUT.Signal=RCC_OSC32_OUT
PC2.Signal=FMC_SDNE0
PC3.Signal=FMC_SDCKE0
PC4.Signal=ETH_RXD0
PC5.Signal=ETH_RXD1
PC6.Signal=SDIO_D6
PC7.Signal=SDIO_D7
PC8.Signal=SDIO_D0
PC9.Signal=SDIO_D1
PD0.Signal=FMC_D2_DA2
PD1.Signal=FMC_D3_DA3
PD10.Signal=FMC_D15_DA15
PD11.Signal=FMC_A16_CLE
PD12.Signal=FMC_A17_ALE
PD13.Signal=FMC_A18
PD14.Signal=FMC_D0_DA0
PD15.Signal=FMC_D1_DA1
PD2.Signal=SDIO_CMD
PD3.Signal=SPI2_SCK
PD4.Signal=FMC_NOE
PD5.Signal=FMC_NWE
PD6.Signal=GPIO_Output
PD7.Signal=FMC_NE1
PD8.Signal=FMC_D13_DA13
PD9.Signal=FMC_D14_DA14
PE0.Signal=FMC_NBL0
PE1.Signal=FMC_NBL1
PE10.Signal=FMC_D7_DA7
PE11.Signal=FMC_D8_DA8
PE12.Signal=FMC_D9_DA9
PE13.Signal=FMC_D10_DA10
PE14.Signal=FMC_D11_DA11
PE15.Signal=FMC_D12_DA12
PE2.Signal=GPIO_Output
PE3.Signal=FMC_A19
PE4.Signal=GPIO_Output
PE5.Signal=GPIO_Output
PE6.Signal=GPIO_Output
PE7.Signal=FMC_D4_DA4
PE8.Signal=FMC_D5_DA5
PE9.Signal=FMC_D6_DA6
PF0.Signal=FMC_A0
PF1.Signal=FMC_A1
PF10.Signal=ADC3_IN8
PF11.Signal=FMC_SDNRAS
PF12.Signal=FMC_A6
PF13.Signal=FMC_A7
PF14.Signal=FMC_A8
PF15.Signal=FMC_A9
PF2.Signal=FMC_A2
PF3.Signal=FMC_A3
PF4.Signal=FMC_A4
PF5.Signal=FMC_A5
PF6.Signal=UART7_RX
PF7.Signal=UART7_TX
PF8.Signal=ADC3_IN6
PF9.Signal=ADC3_IN7
PG0.Signal=FMC_A10
PG1.Signal=FMC_A11
PG11.Signal=ETH_TX_EN
PG15.Signal=FMC_SDNCAS
PG2.Signal=FMC_A12
PG3.Signal=FMC_A13
PG4.Signal=FMC_A14_BA0
PG5.Signal=FMC_A15_BA1
PG6.Signal=GPIO_Output
PG7.Signal=GPIO_Output
PG8.Signal=FMC_SDCLK
PG9.Signal=GPIO_Output
PH0/OSC_IN.Signal=RCC_OSC_IN
PH1/OSC_OUT.Signal=RCC_OSC_OUT

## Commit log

2023-08-02 Added project
    [SoM-STM32F4.PrjPcb]
2023-08-03 Adding files and libraries
    [01 COVER PAGE.SchDoc, 02 BLOCK DIAGRAM.SchDoc, SoM-STM32F4.PcbDoc]
2023-08-03 Adding components
    [02 BLOCK DIAGRAM.SchDoc]
2023-08-04 Added stm
    [01 COVER PAGE.SchDoc, 02 BLOCK DIAGRAM.SchDoc, 03 POWER.SchDoc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]
2023-08-04 Added power regulation
    [01 COVER PAGE.SchDoc, 02 BLOCK DIAGRAM.SchDoc, 03 POWER.SchDoc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]
2023-08-04 power, sdram, nor emmc and secure element wired, but not finished
    [02 BLOCK DIAGRAM.SchDoc, 03 POWER.SchDoc, 04 MCU.SchDoc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]
2023-08-07 Adding modules and connecting them
    [02 BLOCK DIAGRAM.SchDoc, 03 POWER.SchDoc, 04 MCU.SchDoc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]
2023-08-07 MCU power
    [04 MCU.SchDoc, 04-1 MCU.SchDoc]
2023-08-07 CAN interface finished
    [04 MCU.SchDoc, 10 CAN Bus.SchDoc, 11 CONNECTOR.SchDoc]
2023-08-07 Ethernet done
    [09 Ethernet.SchDoc, 10 CAN Bus.SchDoc, 11 CONNECTOR.SchDoc]
2023-08-09 alpha version of schematic
    [03 POWER.SchDoc, 04 MCU.SchDoc, 04-1 MCU.SchDoc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]
2023-08-09 Added pullups
    [03 POWER.SchDoc, 08 Secure Element.SchDoc, 11 CONNECTOR.SchDoc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]
2023-08-09 Added stackup and set up rules
    [SoM-STM32F4.PcbDoc, SoM-STM32F4.PrjPcb]
2023-08-09 Changing main mcu to lqfp because of the bga pin
    [01 COVER PAGE.SchDoc, 03 POWER.SchDoc, 04 MCU.SchDoc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]
2023-08-10 new schematic with lqfp
    [04 MCU.SchDoc, 11 CONNECTOR.SchDoc]
2023-08-10 50% of memory connections done with length matching
    [02 BLOCK DIAGRAM.SchDoc, 04 MCU.SchDoc, 05 SDRAM.SchDoc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]
2023-08-14 routed fmc for sdram finallygit add .!
    [SoM-STM32F4.PcbDoc]
2023-08-15 Matched closely sdram
    [SoM-STM32F4.PcbDoc]
2023-08-15 Changed the eMMC chip, because we physically can't route it
    [04 MCU.SchDoc, 06 NOR Memory.SchDoc, 07 eMMC.SchDoc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]
2023-08-15 emmc internal routing as well to be matched
    [07 eMMC.SchDoc, SoM-STM32F4.PcbDoc]
2023-08-15 routed the ethernet
    [07 eMMC.SchDoc, 09 Ethernet.SchDoc, 11 CONNECTOR.SchDoc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]
2023-08-15 RMII routed, but needs a bit of adjusting
    [SoM-STM32F4.PcbDoc]
2023-08-16 Routed the emmc
    [SoM-STM32F4.PcbDoc]
2023-08-16 Routed one side of the connector with a reorder
    [11 CONNECTOR.SchDoc]
2023-08-16 Connected all connectors
    [11 CONNECTOR.SchDoc]
2023-08-16 Adding rules for clearance on specific traces
    [04 MCU.SchDoc, 05 SDRAM.SchDoc, 07 eMMC.SchDoc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]
2023-08-17 All connections made
    [11 CONNECTOR.SchDoc]
2023-08-17 Cleaning up traces
2023-08-17 Silk v1.1
    [02 BLOCK DIAGRAM.SchDoc, 03 POWER.SchDoc, 04 MCU.SchDoc]
2023-08-17 Board finished, schematic and other details are left
2023-08-17 Deleted nor memory:
    [02 BLOCK DIAGRAM.SchDoc, 07 Secure Element.SchDoc, 08 Ethernet.SchDoc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]
2023-08-17 Added draftsman
    [02 BLOCK DIAGRAM.SchDoc, 03 POWER.SchDoc]
2023-08-18 resolving schematic export
    [01 COVER PAGE.SchDoc, 02 BLOCK DIAGRAM.SchDoc, SoM-STM32F4.PrjPcb]
2023-08-18 Schematic ready
    [03 POWER.SchDoc, 04 MCU.SchDoc, 05 SDRAM.SchDoc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]
2023-08-18 Added some pictures
    [01 COVER PAGE.SchDoc, SoM-STM32F4.PrjPcb]
2023-08-21 Small modifications
    [02 BLOCK DIAGRAM.SchDoc, 03 POWER.SchDoc, 04 MCU.SchDoc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]
2023-08-21 Added export
    [05 SDRAM.SchDoc, 08 Ethernet.SchDoc]
